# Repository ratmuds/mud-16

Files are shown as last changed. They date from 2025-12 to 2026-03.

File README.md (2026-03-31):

# mud-16

a little retro console with a Motorola 68000 and FPGA PPU

# firmware

`ppu.sv` is the Verilog code for the PPU. This is close to what will be the renderer of the game console. `main.cpp` is currently a test bench that gets the display output from the PPU and renders it with Raylib, as well as simulating the CPU bus arbitration and SRAM VRAM access

# features

-   3.5" IPS Display
-   D-pad and ABXY buttons
-   27 MHz FPGA
-   Rechargable Battery
-   512 KB of SRAM

## why

I think that the GameBoy and other retro game console are really cool, and I want to make my own console. But I didn't want to just emulate it, I wanted to use a real retro CPU and make my own PPU (picture processing unit) with a FPGA.

## how

The CPU is the brain pretty much. It handles all the game logic and stuff. It's connected to 512 KB of SRAM which the first part of it is allocated to VRAM. The VRAM is used by the FPGA. The CPU needs to go through level shifters down to 3.3V, and the CPU and FPGA needs to handle bus arbitration properly, otherwise they will fight over the bus and everything will become a mess. The FPGA will request for the bus at the beginning of each frame where they will essentially perform a handshake and the bus will be passed to the FPGA. The FPGA then accesses all the VRAM it needs and then gives back control to the CPU.

The display will be running in 8 bit parallel mode, since SPI is too slow.

## to use

this stuff is WIP

you'll need to flash everything to the FPGA which will load all the necessary data into RAM for the CPU. The Gowin IDE is the app you'll use to flash the Tang Nano.









# Schematic screenshots










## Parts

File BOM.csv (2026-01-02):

Item | Quantity | Cost | Notes | Link
PCB | 1 | $12.10 | JLCPCB PCB | https://jlcpcb.com/
PCB Assembly | 1 | $35.66 | PCB Assembly service | https://jlcpcb.com/
AMS1117-3.3 | 1 | $0.32 | Buck Converter | https://jlcpcb.com/partdetail/Advanced_MonolithicSystems-AMS1117_33/C6186
AMS1117-1.8 | 1 | $0.32 | Buck Converter | https://jlcpcb.com/partdetail/Advanced_MonolithicSystems-AMS1117_18/C6185
74LVC1G04GV | 2 | $0.10 | Shift Register | https://jlcpcb.com/partdetail/TECHPUBLIC-74LVC1G04GV/C19829589
SN74LVC8T245PW | 7 | $1.92 | Level Shifter | https://jlcpcb.com/partdetail/TexasInstruments-SN74LVC8T245PW/C1523276
Female Pin Header | 1 | $2.44 | 1x40 Female Pin Header | https://www.aliexpress.us/item/2255801012106911.html?curPageLogUid=q13fcpg1TWGx&utparam-url=scene%3Asearch|query_from%3A|x_object_id%3A4001198421663|_p_origin_prod%3A
MC68000P12 DIP-64 | 1 | $4.96 | m68k CPU 12 MHz | https://www.ebay.com/itm/315746399382?_skw=MC68000P12&itmmeta=01KCJA2ZDMD3JFW4K6QCRVRQGD|tkp%3ABFBMiveLyuRm
ILI9488 IPS No Touch | 1 | $7.67 | Display | https://www.aliexpress.us/item/3256804339619267.html?mp=1
IC DIP Sockets | 1 | $5.82 | DIP16 sockets | https://www.aliexpress.us/item/3256806149124857.html?curPageLogUid=54rKMPKbiLkA&utparam-url=scene%3Asearch|query_from%3A|x_object_id%3A1005006335439609|_p_origin_prod%3A
AS7C3513B-12TCN | 2 | $12.96 | SRAM | https://www.mouser.com/ProductDetail/Alliance-Memory/AS7C3513B-12TCN?qs=E5c5%252Bmu3i3%252BBrpzFfz%2FKzg%3D%3D
FH12-40S-0.5SH(55) | 1 | $0.62 | 40 Pin FPC Connector (display) | https://jlcpcb.com/partdetail/HRS_Hirose-FH12_40S_0_5SH_55/C202114
SN74HC165N | 2 | $1.17 | Shift Register | https://jlcpcb.com/partdetail/Ti-SN74HC165N/C2909
74HC595D | 2 | $0.53 | Shift Register | https://jlcpcb.com/partdetail/Nexperia-74HC595D_118/C5947
F32R-1A7H1-11040 | 1 | $0.91 | 40P FFC/FPC Connector | https://jlcpcb.com/partdetail/Amphenol-F32R_1A7H1_11040/C3169456
0805W8F3300T5E | 1 | $0.01 | 330Ω Resistor | https://jlcpcb.com/partdetail/UniRoyal-0805W8F3300T5E/C17630
WS2812B-HS01/W | 1 | $0.09 | RGB LED | https://jlcpcb.com/partdetail/Worldsemi-WS2812B_HS01_W/C22371521
CL21A226MAQNNNE | 2 | $0.05 | 22uF Capacitor | https://jlcpcb.com/partdetail/Samsung-CL21A226MAQNNNE/C45783
62684-501100ALF | 2 | $1.29 | 50P FFC/FPC Connector | https://jlcpcb.com/partdetail/Amphenol-62684_501100ALF/C180244
0805W8F1002T5E | 1 | $0.01 | 10kΩ Resistor | https://jlcpcb.com/partdetail/UniRoyal-0805W8F1002T5E/C17414
CL21B105KBFNNNE | 1 | $0.01 | 1uF Capacitor | https://jlcpcb.com/partdetail/Samsung-CL21B105KBFNNNE/C28323
CL21A106KAYNNNE | 1 | $0.02 | 10uF Capacitor | https://jlcpcb.com/partdetail/Samsung-CL21A106KAYNNNE/C15850
CL21B104KCFNNNE | 1 | $0.01 | 100nF Capacitor | https://jlcpcb.com/partdetail/Samsung-CL21B104KCFNNNE/C28233

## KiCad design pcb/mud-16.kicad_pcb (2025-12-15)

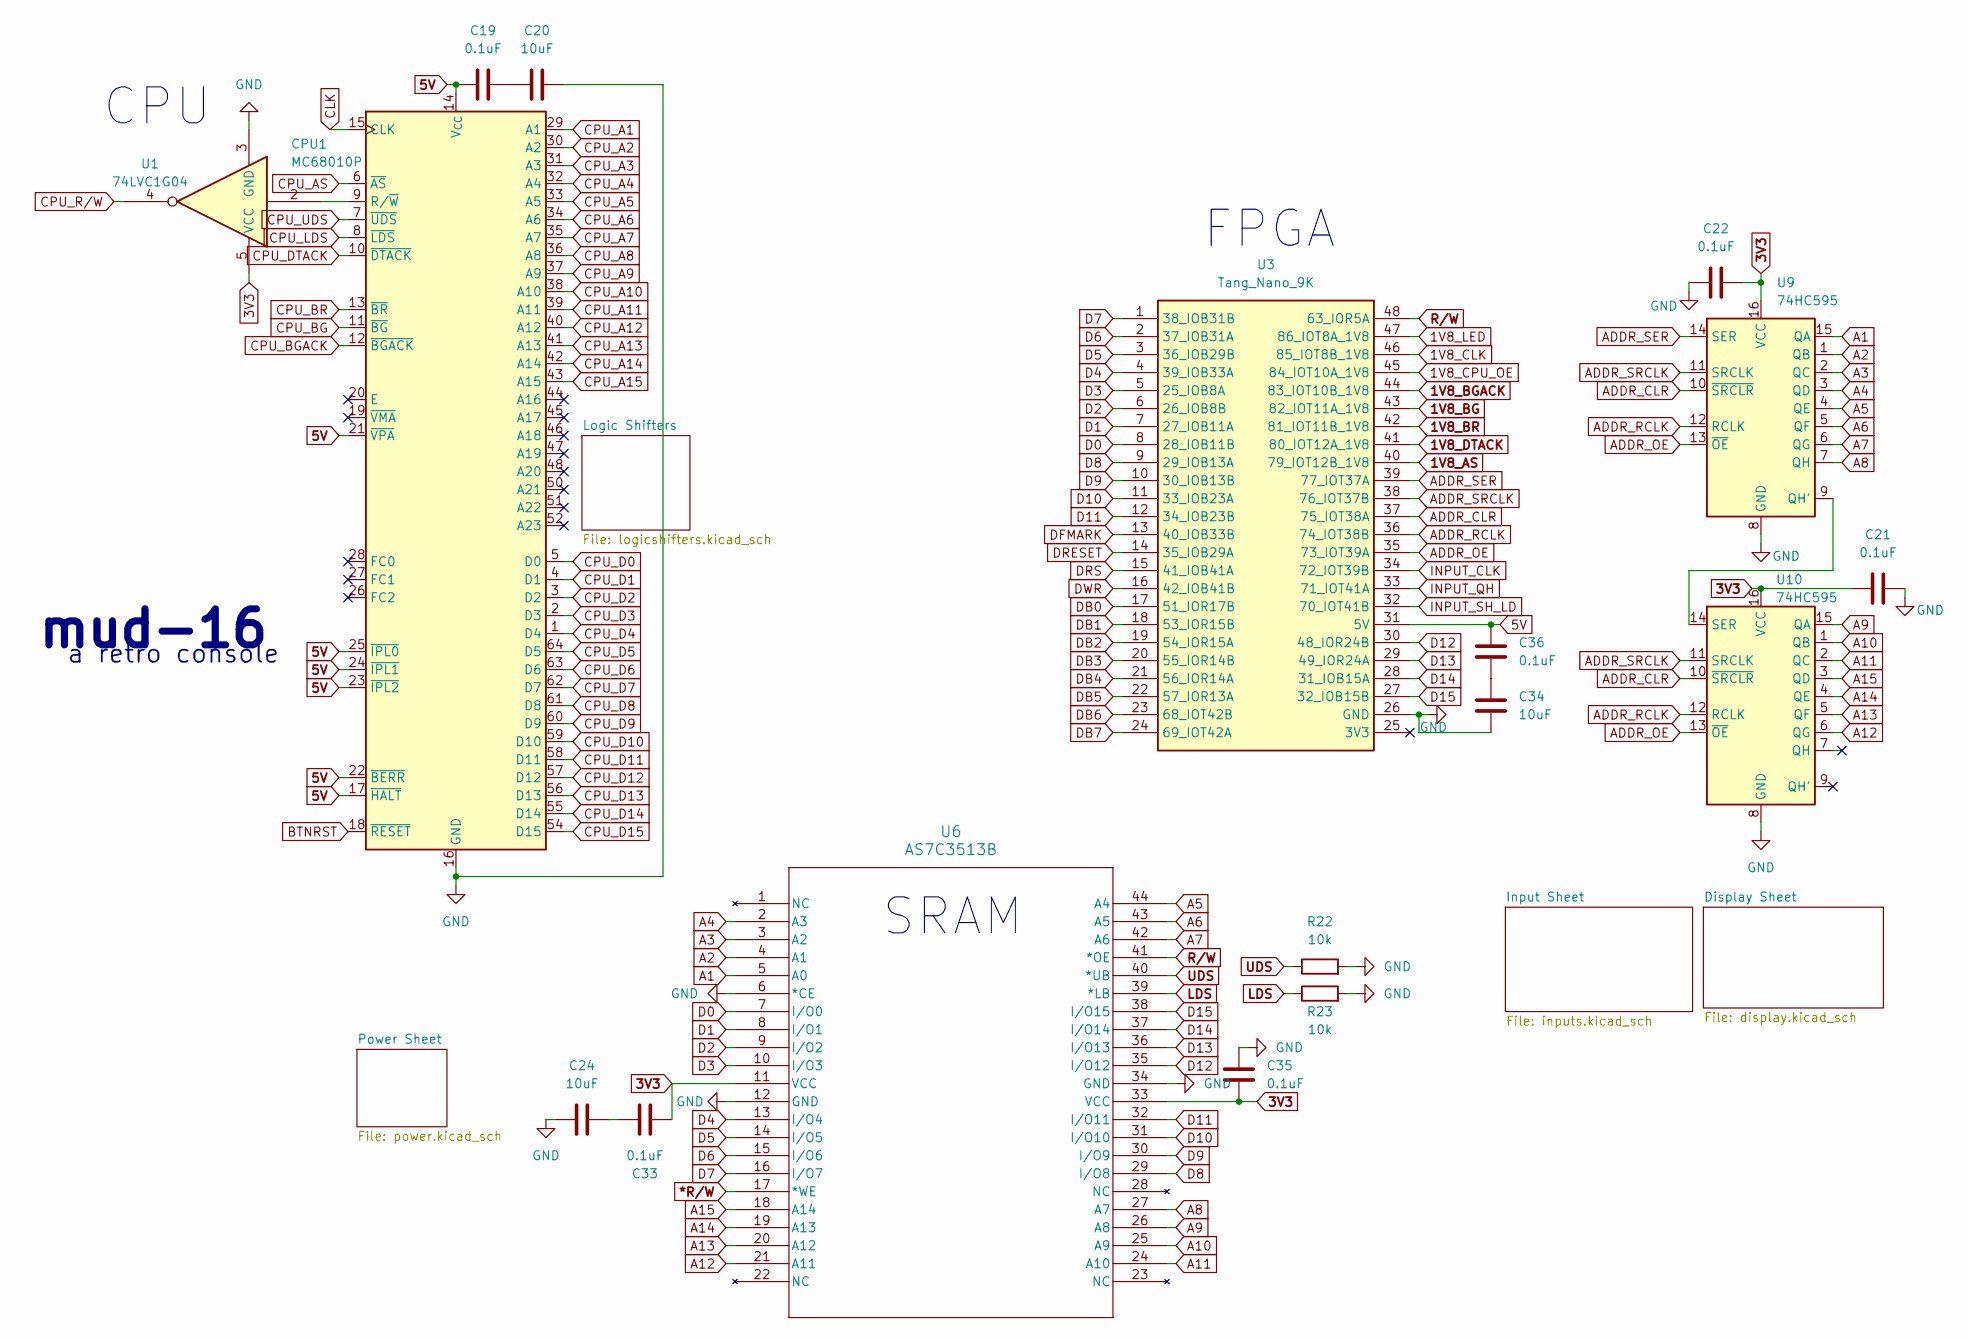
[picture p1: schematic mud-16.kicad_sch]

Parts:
C19, C21, C22, C33, C35, C36: 0.1uF; C_0805_2012Metric_Pad1.18x1.45mm_HandSolder
C20, C24, C34: 10uF; C_0805_2012Metric_Pad1.18x1.45mm_HandSolder
CPU1: MC68010P; DIP-64_W22.86mm
R22, R23: 10k; R_0805_2012Metric_Pad1.20x1.40mm_HandSolder
U1: 74LVC1G04; SOT-23-5_HandSoldering
U3: Tang_Nano_9K; DIP-48_TangNano9K
U6: AS7C3513B; TSOP-44_10P2X18P4_ALL
U9, U10: 74HC595; SOIC-16_3.9x9.9mm_P1.27mm

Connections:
1V8_AS: U3.40 (79_IOT12B_1V8); also elsewhere on the board
1V8_BG: U3.43 (82_IOT11A_1V8); also elsewhere on the board
1V8_BGACK: U3.44 (83_IOT10B_1V8); also elsewhere on the board
1V8_BR: U3.42 (81_IOT11B_1V8); also elsewhere on the board
1V8_CLK: U3.46 (85_IOT8B_1V8); also elsewhere on the board
1V8_CPU_OE: U3.45 (84_IOT10A_1V8); also elsewhere on the board
1V8_DTACK: U3.41 (80_IOT12A_1V8); also elsewhere on the board
1V8_LED: U3.47 (86_IOT8A_1V8); also elsewhere on the board
3V3: C21.1, C22.2, C33.1, C35.2, U1.5 (VCC), U6.11 (VCC), U6.33 (VCC), U9.16 (VCC), U10.16 (VCC); also elsewhere on the board
5V: C19.1, C36.1, CPU1.14 (V_{CC}), CPU1.17 (~HALT), CPU1.21 (~VPA), CPU1.22 (~BERR), CPU1.23 (~IPL2), CPU1.24 (~IPL1), CPU1.25 (~IPL0), CPU1.49 (V_{CC}), U3.31 (5V); also elsewhere on the board
*R/W: U6.17 (*WE); also elsewhere on the board
A1: U6.5 (A0), U9.15 (QA); also elsewhere on the board
A2: U6.4 (A1), U9.1 (QB); also elsewhere on the board
A3: U6.3 (A2), U9.2 (QC); also elsewhere on the board
A4: U6.2 (A3), U9.3 (QD); also elsewhere on the board
A5: U6.44 (A4), U9.4 (QE); also elsewhere on the board
A6: U6.43 (A5), U9.5 (QF); also elsewhere on the board
A7: U6.42 (A6), U9.6 (QG); also elsewhere on the board
A8: U6.27 (A7), U9.7 (QH); also elsewhere on the board
A9: U6.26 (A8), U10.15 (QA); also elsewhere on the board
A10: U6.25 (A9), U10.1 (QB); also elsewhere on the board
A11: U6.24 (A10), U10.2 (QC); also elsewhere on the board
A12: U6.21 (A11), U10.6 (QG); also elsewhere on the board
A13: U6.20 (A12), U10.5 (QF); also elsewhere on the board
A14: U6.19 (A13), U10.4 (QE); also elsewhere on the board
A15: U6.18 (A14), U10.3 (QD); also elsewhere on the board
ADDR_CLR: U3.37 (75_IOT38A), U9.10 (~SRCLR), U10.10 (~SRCLR)
ADDR_OE: U3.35 (73_IOT39A), U9.13 (~OE), U10.13 (~OE)
ADDR_RCLK: U3.36 (74_IOT38B), U9.12 (RCLK), U10.12 (RCLK)
ADDR_SER: U3.39 (77_IOT37A), U9.14 (SER)
ADDR_SRCLK: U3.38 (76_IOT37B), U9.11 (SRCLK), U10.11 (SRCLK)
BTNRST: CPU1.18 (~RESET); also elsewhere on the board
CLK: CPU1.15 (CLK); also elsewhere on the board
CPU_A1: CPU1.29 (A1); also elsewhere on the board
CPU_A2: CPU1.30 (A2); also elsewhere on the board
CPU_A3: CPU1.31 (A3); also elsewhere on the board
CPU_A4: CPU1.32 (A4); also elsewhere on the board
CPU_A5: CPU1.33 (A5); also elsewhere on the board
CPU_A6: CPU1.34 (A6); also elsewhere on the board
CPU_A7: CPU1.35 (A7); also elsewhere on the board
CPU_A8: CPU1.36 (A8); also elsewhere on the board
CPU_A9: CPU1.37 (A9); also elsewhere on the board
CPU_A10: CPU1.38 (A10); also elsewhere on the board
CPU_A11: CPU1.39 (A11); also elsewhere on the board
CPU_A12: CPU1.40 (A12); also elsewhere on the board
CPU_A13: CPU1.41 (A13); also elsewhere on the board
CPU_A14: CPU1.42 (A14); also elsewhere on the board
CPU_A15: CPU1.43 (A15); also elsewhere on the board
CPU_AS: CPU1.6 (~AS); also elsewhere on the board
CPU_BG: CPU1.11 (~BG); also elsewhere on the board
CPU_BGACK: CPU1.12 (~BGACK); also elsewhere on the board
CPU_BR: CPU1.13 (~BR); also elsewhere on the board
CPU_D0: CPU1.5 (D0); also elsewhere on the board
CPU_D1: CPU1.4 (D1); also elsewhere on the board
CPU_D2: CPU1.3 (D2); also elsewhere on the board
CPU_D3: CPU1.2 (D3); also elsewhere on the board
CPU_D4: CPU1.1 (D4); also elsewhere on the board
CPU_D5: CPU1.64 (D5); also elsewhere on the board
CPU_D6: CPU1.63 (D6); also elsewhere on the board
CPU_D7: CPU1.62 (D7); also elsewhere on the board
CPU_D8: CPU1.61 (D8); also elsewhere on the board
CPU_D9: CPU1.60 (D9); also elsewhere on the board
CPU_D10: CPU1.59 (D10); also elsewhere on the board
CPU_D11: CPU1.58 (D11); also elsewhere on the board
CPU_D12: CPU1.57 (D12); also elsewhere on the board
CPU_D13: CPU1.56 (D13); also elsewhere on the board
CPU_D14: CPU1.55 (D14); also elsewhere on the board
CPU_D15: CPU1.54 (D15); also elsewhere on the board
CPU_DTACK: CPU1.10 (~DTACK); also elsewhere on the board
CPU_LDS: CPU1.8 (~LDS); also elsewhere on the board
CPU_R/W: U1.4; also elsewhere on the board
CPU_UDS: CPU1.7 (~UDS); also elsewhere on the board
D0: U3.8 (28_IOB11B), U6.7 (I/O0); also elsewhere on the board
D1: U3.7 (27_IOB11A), U6.8 (I/O1); also elsewhere on the board
D2: U3.6 (26_IOB8B), U6.9 (I/O2); also elsewhere on the board
D3: U3.5 (25_IOB8A), U6.10 (I/O3); also elsewhere on the board
D4: U3.4 (39_IOB33A), U6.13 (I/O4); also elsewhere on the board
D5: U3.3 (36_IOB29B), U6.14 (I/O5); also elsewhere on the board
D6: U3.2 (37_IOB31A), U6.15 (I/O6); also elsewhere on the board
D7: U3.1 (38_IOB31B), U6.16 (I/O7); also elsewhere on the board
D8: U3.9 (29_IOB13A), U6.29 (I/O8); also elsewhere on the board
D9: U3.10 (30_IOB13B), U6.30 (I/O9); also elsewhere on the board
D10: U3.11 (33_IOB23A), U6.31 (I/O10); also elsewhere on the board
D11: U3.12 (34_IOB23B), U6.32 (I/O11); also elsewhere on the board
D12: U3.30 (48_IOR24B), U6.35 (I/O12); also elsewhere on the board
D13: U3.29 (49_IOR24A), U6.36 (I/O13); also elsewhere on the board
D14: U3.28 (31_IOB15A), U6.37 (I/O14); also elsewhere on the board
D15: U3.27 (32_IOB15B), U6.38 (I/O15); also elsewhere on the board
DB0: U3.17 (51_IOR17B); also elsewhere on the board
DB1: U3.18 (53_IOR15B); also elsewhere on the board
DB2: U3.19 (54_IOR15A); also elsewhere on the board
DB3: U3.20 (55_IOR14B); also elsewhere on the board
DB4: U3.21 (56_IOR14A); also elsewhere on the board
DB5: U3.22 (57_IOR13A); also elsewhere on the board
DB6: U3.23 (68_IOT42B); also elsewhere on the board
DB7: U3.24 (69_IOT42A); also elsewhere on the board
DFMARK: U3.13 (40_IOB33B); also elsewhere on the board
DRESET: U3.14 (35_IOB29A); also elsewhere on the board
DRS: U3.15 (41_IOB41A); also elsewhere on the board
DWR: U3.16 (42_IOB41B); also elsewhere on the board
GND: C20.2, C21.2, C22.1, C24.1, C34.2, C35.1, CPU1.16 (GND), CPU1.53 (GND), R22.2, R23.2, U1.3 (GND), U3.26 (GND), U6.6 (*CE), U6.12 (GND), U6.34 (GND), U9.8 (GND), U10.8 (GND); also elsewhere on the board
INPUT_CLK: U3.34 (72_IOT39B); also elsewhere on the board
INPUT_QH: U3.33 (71_IOT41A); also elsewhere on the board
INPUT_SH_LD: U3.32 (70_IOT41B); also elsewhere on the board
LDS: R23.1, U6.39 (*LB); also elsewhere on the board
unnamed: C19.2, C20.1
unnamed: C24.2, C33.2
unnamed: C34.1, C36.2
unnamed: CPU1.9 (R/~W), U1.2
unnamed: U9.9 (QH'), U10.14 (SER)
R/W: U3.48 (63_IOR5A), U6.41 (*OE); also elsewhere on the board
UDS: R22.1, U6.40 (*UB); also elsewhere on the board

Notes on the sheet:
mud-16
SRAM
FPGA
a retro console
CPU

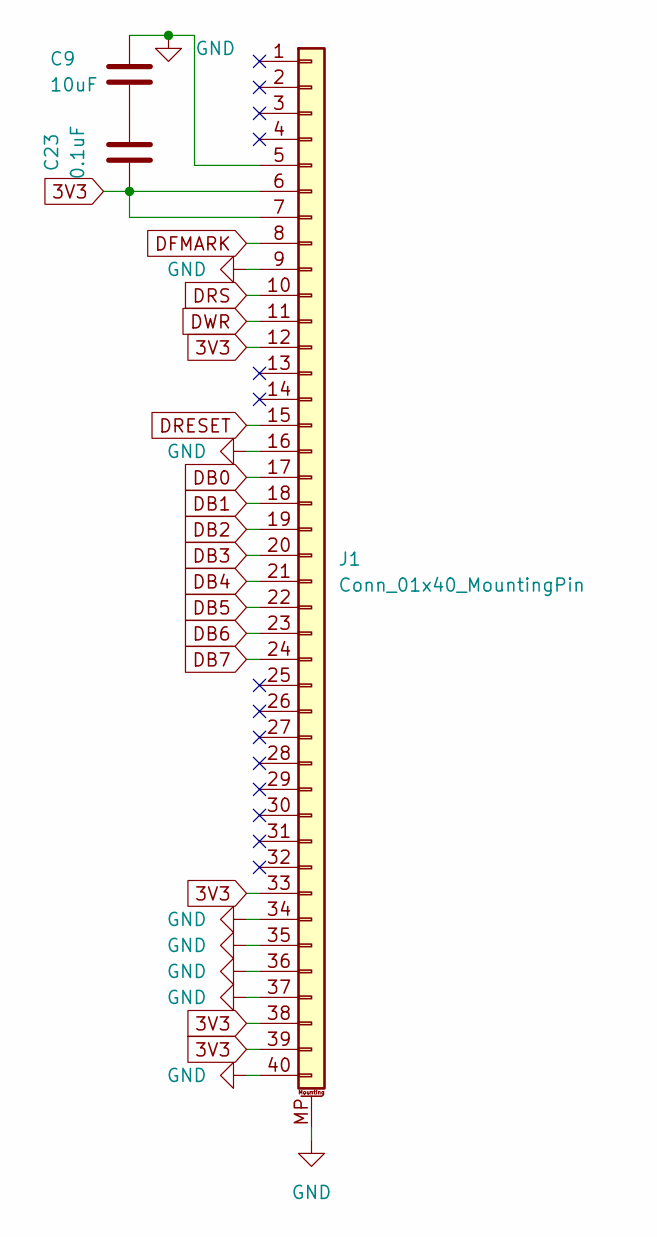
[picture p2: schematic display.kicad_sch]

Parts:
C9: 10uF; C_0805_2012Metric_Pad1.18x1.45mm_HandSolder
C23: 0.1uF; C_0805_2012Metric_Pad1.18x1.45mm_HandSolder
J1: Conn_01x40_MountingPin; Amphenol_F32R-1A7x1-11040_1x40-1MP_P0.5mm_Horizontal

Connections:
3V3: C23.1, J1.6, J1.7, J1.12, J1.33, J1.38, J1.39; also elsewhere on the board
DB0: J1.17; also elsewhere on the board
DB1: J1.18; also elsewhere on the board
DB2: J1.19; also elsewhere on the board
DB3: J1.20; also elsewhere on the board
DB4: J1.21; also elsewhere on the board
DB5: J1.22; also elsewhere on the board
DB6: J1.23; also elsewhere on the board
DB7: J1.24; also elsewhere on the board
DFMARK: J1.8; also elsewhere on the board
DRESET: J1.15; also elsewhere on the board
DRS: J1.10; also elsewhere on the board
DWR: J1.11; also elsewhere on the board
GND: C9.1, J1.5, J1.9, J1.16, J1.34, J1.35, J1.36, J1.37, J1.40, J1.MP (MountPin); also elsewhere on the board
unnamed: C9.2, C23.2

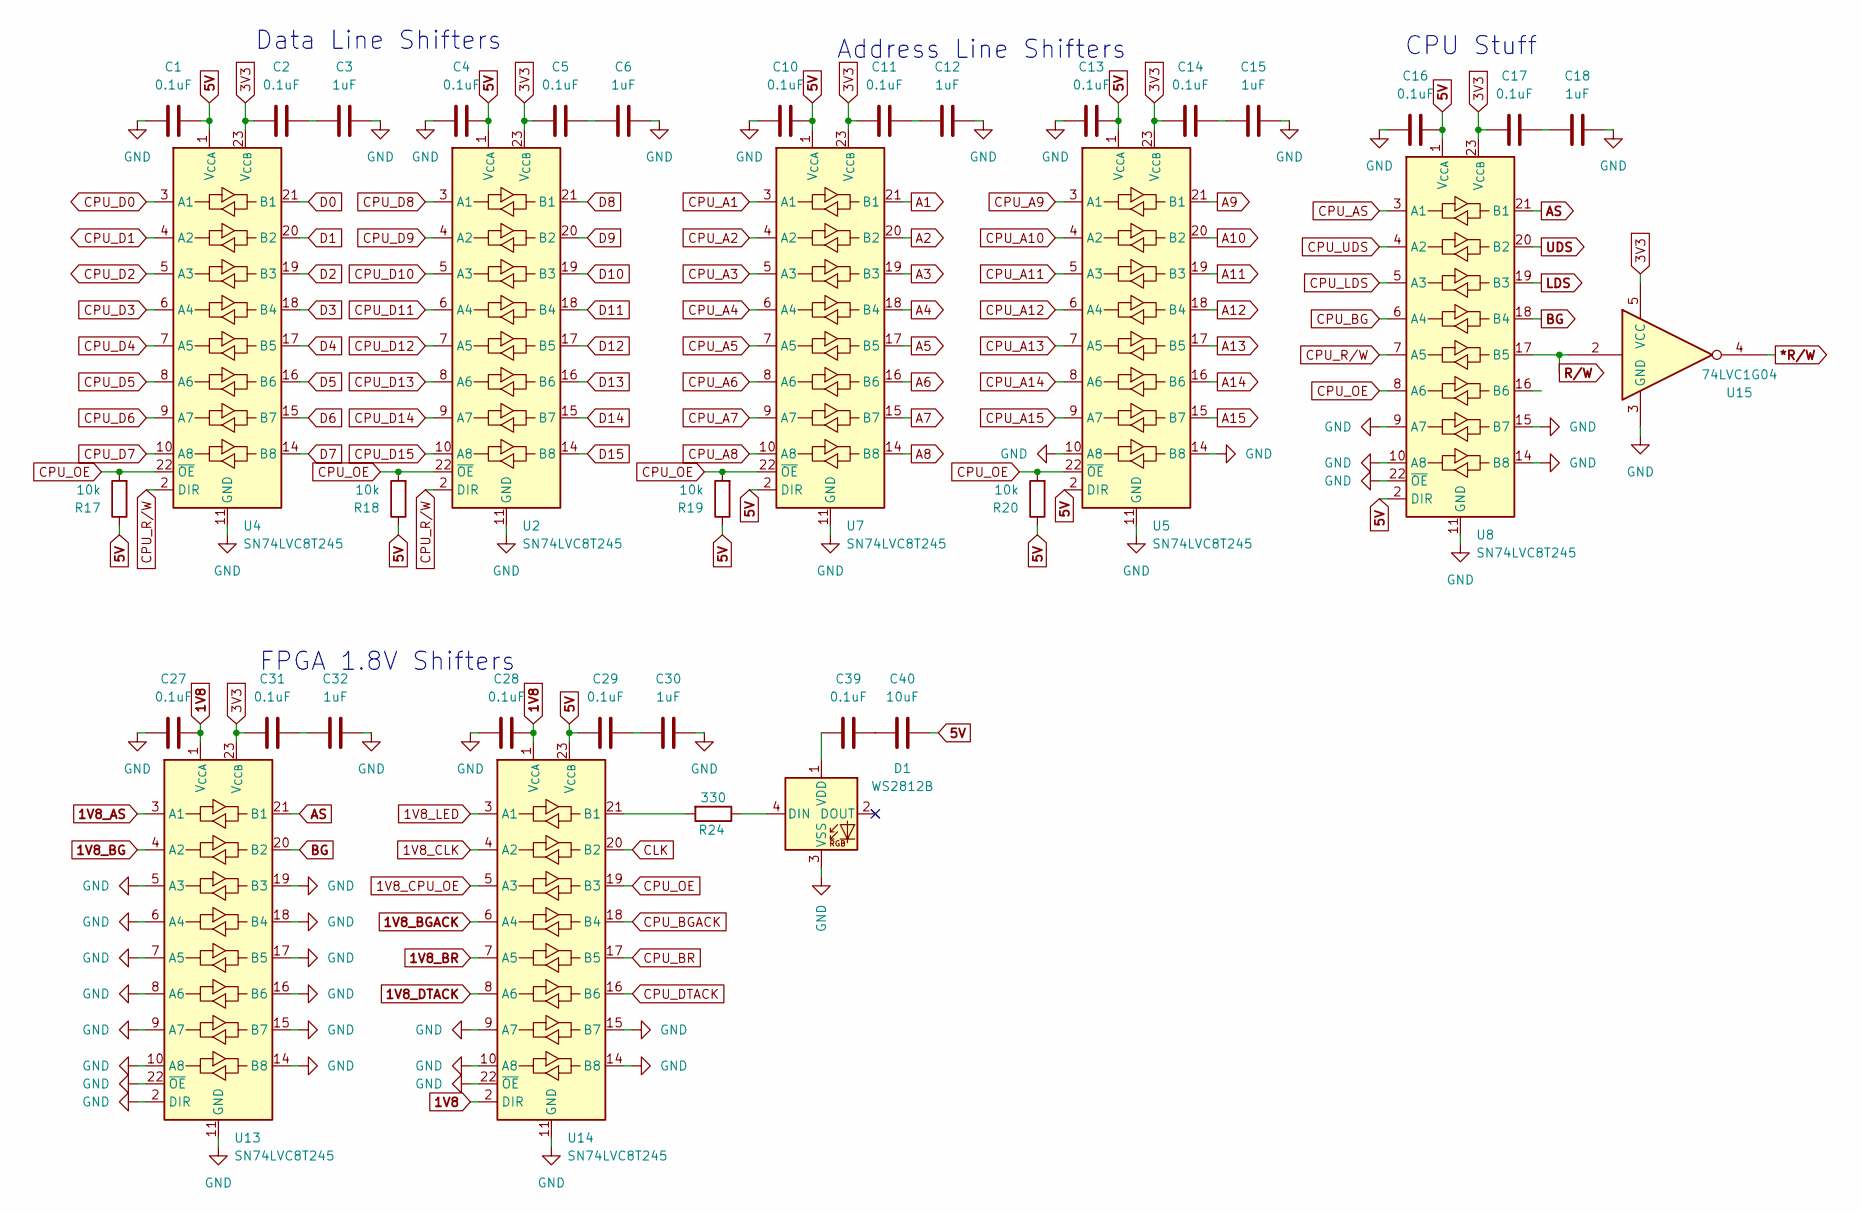
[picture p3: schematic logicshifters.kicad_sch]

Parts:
C1, C2, C4, C5, C10, C11, C13, C14, C16, C17, C27, C28, C29, C31, C39: 0.1uF; C_0805_2012Metric_Pad1.18x1.45mm_HandSolder
C3, C6, C12, C15, C18, C30, C32: 1uF; C_0805_2012Metric_Pad1.18x1.45mm_HandSolder
C40: 10uF; C_0805_2012Metric_Pad1.18x1.45mm_HandSolder
D1: WS2812B; LED_WS2812B_PLCC4_5.0x5.0mm_P3.2mm
R17, R18, R19, R20: 10k; R_0805_2012Metric_Pad1.20x1.40mm_HandSolder
R24: 330; R_0805_2012Metric_Pad1.20x1.40mm_HandSolder
U2, U4, U5, U7, U8, U13, U14: SN74LVC8T245; TSSOP-24_4.4x7.8mm_P0.65mm
U15: 74LVC1G04; SOT-23-5_HandSoldering

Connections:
1V8: C27.2, C28.2, U13.1 (V_{CCA}), U14.1 (V_{CCA}), U14.2 (DIR); also elsewhere on the board
1V8_AS: U13.3 (A1); also elsewhere on the board
1V8_BG: U13.4 (A2); also elsewhere on the board
1V8_BGACK: U14.6 (A4); also elsewhere on the board
1V8_BR: U14.7 (A5); also elsewhere on the board
1V8_CLK: U14.4 (A2); also elsewhere on the board
1V8_CPU_OE: U14.5 (A3); also elsewhere on the board
1V8_DTACK: U14.8 (A6); also elsewhere on the board
1V8_LED: U14.3 (A1); also elsewhere on the board
3V3: C2.1, C5.1, C11.1, C14.1, C17.1, C31.1, U2.23 (V_{CCB}), U2.24 (V_{CCB}), U4.23 (V_{CCB}), U4.24 (V_{CCB}), U5.23 (V_{CCB}), U5.24 (V_{CCB}), U7.23 (V_{CCB}), U7.24 (V_{CCB}), U8.23 (V_{CCB}), U8.24 (V_{CCB}), U13.23 (V_{CCB}), U13.24 (V_{CCB}), U15.5 (VCC); also elsewhere on the board
5V: C1.2, C4.2, C10.2, C13.2, C16.2, C29.1, C40.2, R17.1, R18.1, R19.1, R20.1, U2.1 (V_{CCA}), U4.1 (V_{CCA}), U5.1 (V_{CCA}), U5.2 (DIR), U7.1 (V_{CCA}), U7.2 (DIR), U8.1 (V_{CCA}), U8.2 (DIR), U14.23 (V_{CCB}), U14.24 (V_{CCB}); also elsewhere on the board
*R/W: U15.4; also elsewhere on the board
A1: U7.21 (B1); also elsewhere on the board
A2: U7.20 (B2); also elsewhere on the board
A3: U7.19 (B3); also elsewhere on the board
A4: U7.18 (B4); also elsewhere on the board
A5: U7.17 (B5); also elsewhere on the board
A6: U7.16 (B6); also elsewhere on the board
A7: U7.15 (B7); also elsewhere on the board
A8: U7.14 (B8); also elsewhere on the board
A9: U5.21 (B1); also elsewhere on the board
A10: U5.20 (B2); also elsewhere on the board
A11: U5.19 (B3); also elsewhere on the board
A12: U5.18 (B4); also elsewhere on the board
A13: U5.17 (B5); also elsewhere on the board
A14: U5.16 (B6); also elsewhere on the board
A15: U5.15 (B7); also elsewhere on the board
AS: U8.21 (B1), U13.21 (B1)
BG: U8.18 (B4), U13.20 (B2)
CLK: U14.20 (B2); also elsewhere on the board
CPU_A1: U7.3 (A1); also elsewhere on the board
CPU_A2: U7.4 (A2); also elsewhere on the board
CPU_A3: U7.5 (A3); also elsewhere on the board
CPU_A4: U7.6 (A4); also elsewhere on the board
CPU_A5: U7.7 (A5); also elsewhere on the board
CPU_A6: U7.8 (A6); also elsewhere on the board
CPU_A7: U7.9 (A7); also elsewhere on the board
CPU_A8: U7.10 (A8); also elsewhere on the board
CPU_A9: U5.3 (A1); also elsewhere on the board
CPU_A10: U5.4 (A2); also elsewhere on the board
CPU_A11: U5.5 (A3); also elsewhere on the board
CPU_A12: U5.6 (A4); also elsewhere on the board
CPU_A13: U5.7 (A5); also elsewhere on the board
CPU_A14: U5.8 (A6); also elsewhere on the board
CPU_A15: U5.9 (A7); also elsewhere on the board
CPU_AS: U8.3 (A1); also elsewhere on the board
CPU_BG: U8.6 (A4); also elsewhere on the board
CPU_BGACK: U14.18 (B4); also elsewhere on the board
CPU_BR: U14.17 (B5); also elsewhere on the board
CPU_D0: U4.3 (A1); also elsewhere on the board
CPU_D1: U4.4 (A2); also elsewhere on the board
CPU_D2: U4.5 (A3); also elsewhere on the board
CPU_D3: U4.6 (A4); also elsewhere on the board
CPU_D4: U4.7 (A5); also elsewhere on the board
CPU_D5: U4.8 (A6); also elsewhere on the board
CPU_D6: U4.9 (A7); also elsewhere on the board
CPU_D7: U4.10 (A8); also elsewhere on the board
CPU_D8: U2.3 (A1); also elsewhere on the board
CPU_D9: U2.4 (A2); also elsewhere on the board
CPU_D10: U2.5 (A3); also elsewhere on the board
CPU_D11: U2.6 (A4); also elsewhere on the board
CPU_D12: U2.7 (A5); also elsewhere on the board
CPU_D13: U2.8 (A6); also elsewhere on the board
CPU_D14: U2.9 (A7); also elsewhere on the board
CPU_D15: U2.10 (A8); also elsewhere on the board
CPU_DTACK: U14.16 (B6); also elsewhere on the board
CPU_LDS: U8.5 (A3); also elsewhere on the board
CPU_OE: R17.2, R18.2, R19.2, R20.2, U2.22 (~OE), U4.22 (~OE), U5.22 (~OE), U7.22 (~OE), U8.8 (A6), U14.19 (B3)
CPU_R/W: U2.2 (DIR), U4.2 (DIR), U8.7 (A5); also elsewhere on the board
CPU_UDS: U8.4 (A2); also elsewhere on the board
D0: U4.21 (B1); also elsewhere on the board
D1: U4.20 (B2); also elsewhere on the board
D2: U4.19 (B3); also elsewhere on the board
D3: U4.18 (B4); also elsewhere on the board
D4: U4.17 (B5); also elsewhere on the board
D5: U4.16 (B6); also elsewhere on the board
D6: U4.15 (B7); also elsewhere on the board
D7: U4.14 (B8); also elsewhere on the board
D8: U2.21 (B1); also elsewhere on the board
D9: U2.20 (B2); also elsewhere on the board
D10: U2.19 (B3); also elsewhere on the board
D11: U2.18 (B4); also elsewhere on the board
D12: U2.17 (B5); also elsewhere on the board
D13: U2.16 (B6); also elsewhere on the board
D14: U2.15 (B7); also elsewhere on the board
D15: U2.14 (B8); also elsewhere on the board
GND: C1.1, C3.2, C4.1, C6.2, C10.1, C12.2, C13.1, C15.2, C16.1, C18.2, C27.1, C28.1, C30.2, C32.2, D1.3 (VSS), U2.11 (GND), U2.12 (GND), U2.13 (GND), U4.11 (GND), U4.12 (GND), U4.13 (GND), U5.10 (A8), U5.11 (GND), U5.12 (GND), U5.13 (GND), U5.14 (B8), U7.11 (GND), U7.12 (GND), U7.13 (GND), U8.9 (A7), U8.10 (A8), U8.11 (GND), U8.12 (GND), U8.13 (GND), U8.14 (B8), U8.15 (B7), U8.22 (~OE), U13.2 (DIR), U13.5 (A3), U13.6 (A4), U13.7 (A5), U13.8 (A6), U13.9 (A7), U13.10 (A8), U13.11 (GND), U13.12 (GND), U13.13 (GND), U13.14 (B8), U13.15 (B7), U13.16 (B6), U13.17 (B5), U13.18 (B4), U13.19 (B3), U13.22 (~OE), U14.9 (A7), U14.10 (A8), U14.11 (GND), U14.12 (GND), U14.13 (GND), U14.14 (B8), U14.15 (B7), U14.22 (~OE), U15.3 (GND); also elsewhere on the board
LDS: U8.19 (B3); also elsewhere on the board
unnamed: C2.2, C3.1
unnamed: C5.2, C6.1
unnamed: C11.2, C12.1
unnamed: C14.2, C15.1
unnamed: C17.2, C18.1
unnamed: C29.2, C30.1
unnamed: C31.2, C32.1
unnamed: C39.2, C40.1
unnamed: D1.4 (DIN), R24.1
unnamed: C39.1, D1.1 (VDD)
unnamed: R24.2, U14.21 (B1)
R/W: U8.17 (B5), U15.2; also elsewhere on the board
UDS: U8.20 (B2); also elsewhere on the board

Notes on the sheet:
CPU Stuff
Data Line Shifters
FPGA 1.8V Shifters
Address Line Shifters

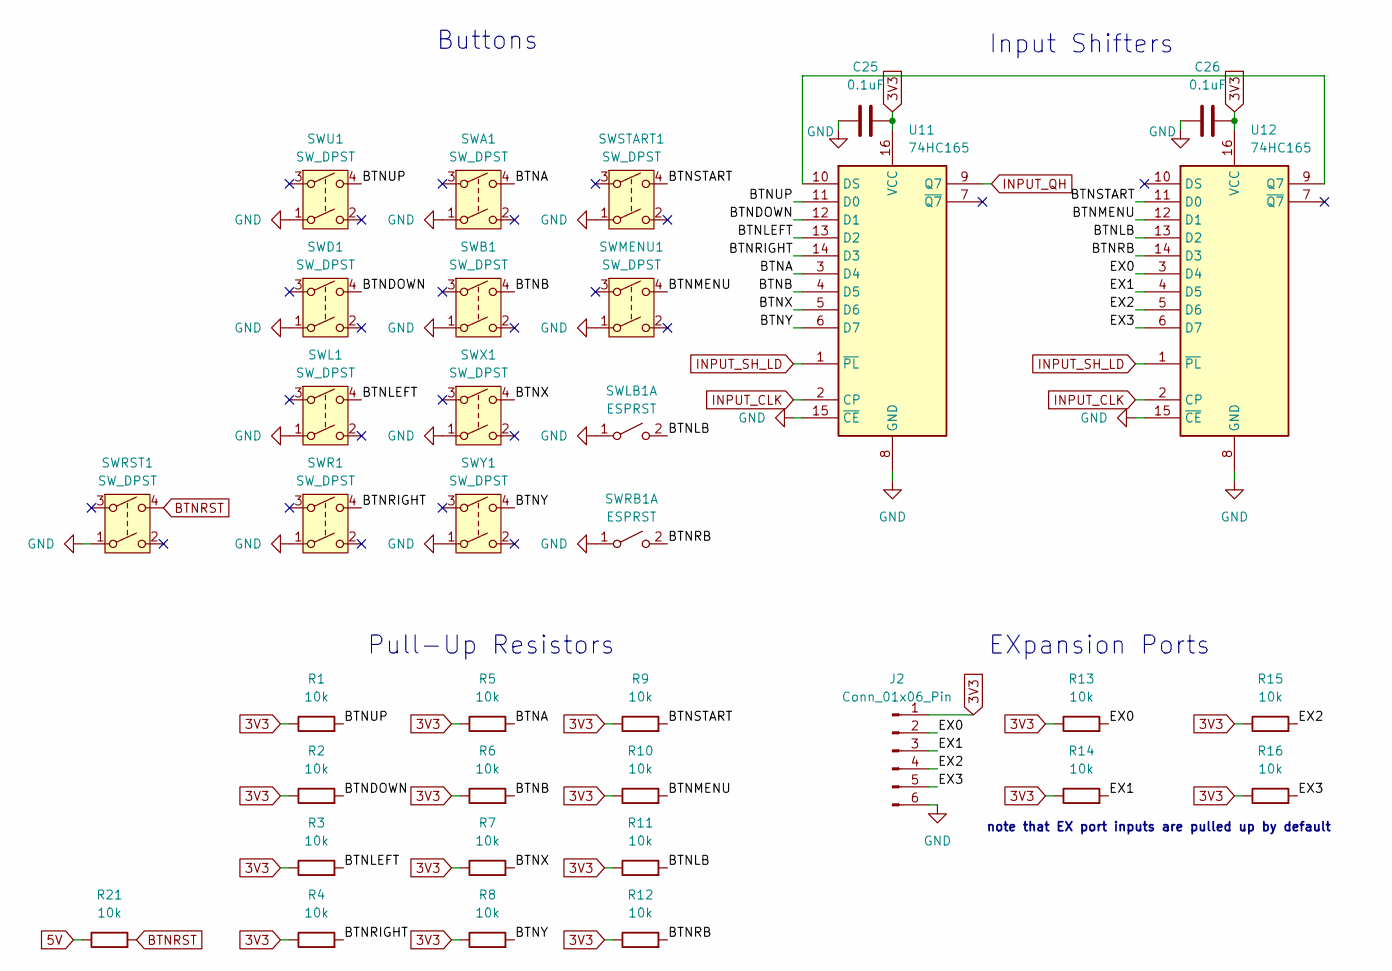
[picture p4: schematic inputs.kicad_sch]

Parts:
C25, C26: 0.1uF; C_0805_2012Metric_Pad1.18x1.45mm_HandSolder
J2: Conn_01x06_Pin; PinSocket_1x06_P2.54mm_Vertical
R1, R2, R3, R4, R5, R6, R7, R8, R9, R10, R11, R12, R13, R14, R15, R16, R21: 10k; R_0805_2012Metric_Pad1.20x1.40mm_HandSolder
SWA1: SW_DPST; SW_PUSH_6mm
SWB1: SW_DPST; SW_PUSH_6mm
SWD1: SW_DPST; SW_PUSH_6mm
SWL1: SW_DPST; SW_PUSH_6mm
SWLB1: ESPRST; SW_SIDE_PUSH_3x6mm
SWMENU1: SW_DPST; SW_PUSH_6mm
SWR1: SW_DPST; SW_PUSH_6mm
SWRB1: ESPRST; SW_SIDE_PUSH_3x6mm
SWRST1: SW_DPST; SW_PUSH_6mm
SWSTART1: SW_DPST; SW_PUSH_6mm
SWU1: SW_DPST; SW_PUSH_6mm
SWX1: SW_DPST; SW_PUSH_6mm
SWY1: SW_DPST; SW_PUSH_6mm
U11, U12: 74HC165; DIP-16_W7.62mm

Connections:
3V3: C25.2, C26.2, J2.1, R1.1, R2.1, R3.1, R4.1, R5.1, R6.1, R7.1, R8.1, R9.1, R10.1, R11.1, R12.1, R13.1, R14.1, R15.1, R16.1, U11.16 (VCC), U12.16 (VCC); also elsewhere on the board
5V: R21.1; also elsewhere on the board
/Input Sheet/BTNA: R5.2, SWA1.4, U11.3 (D4)
/Input Sheet/BTNB: R6.2, SWB1.4, U11.4 (D5)
/Input Sheet/BTNDOWN: R2.2, SWD1.4, U11.12 (D1)
/Input Sheet/BTNLB: R11.2, SWLB1.2 (B), U12.13 (D2)
/Input Sheet/BTNLEFT: R3.2, SWL1.4, U11.13 (D2)
/Input Sheet/BTNMENU: R10.2, SWMENU1.4, U12.12 (D1)
/Input Sheet/BTNRB: R12.2, SWRB1.2 (B), U12.14 (D3)
/Input Sheet/BTNRIGHT: R4.2, SWR1.4, U11.14 (D3)
/Input Sheet/BTNSTART: R9.2, SWSTART1.4, U12.11 (D0)
/Input Sheet/BTNUP: R1.2, SWU1.4, U11.11 (D0)
/Input Sheet/BTNX: R7.2, SWX1.4, U11.5 (D6)
/Input Sheet/BTNY: R8.2, SWY1.4, U11.6 (D7)
/Input Sheet/EX0: J2.2, R13.2, U12.3 (D4)
/Input Sheet/EX1: J2.3, R14.2, U12.4 (D5)
/Input Sheet/EX2: J2.4, R15.2, U12.5 (D6)
/Input Sheet/EX3: J2.5, R16.2, U12.6 (D7)
BTNRST: R21.2, SWRST1.4; also elsewhere on the board
GND: C25.1, C26.1, J2.6, SWA1.1, SWB1.1, SWD1.1, SWL1.1, SWLB1.1 (A), SWMENU1.1, SWR1.1, SWRB1.1 (A), SWRST1.1, SWSTART1.1, SWU1.1, SWX1.1, SWY1.1, U11.8 (GND), U11.15 (~CE), U12.8 (GND), U12.15 (~CE); also elsewhere on the board
INPUT_CLK: U11.2 (CP), U12.2 (CP); also elsewhere on the board
INPUT_QH: U11.9 (Q7); also elsewhere on the board
INPUT_SH_LD: U11.1 (~PL), U12.1 (~PL); also elsewhere on the board
unnamed: U11.10 (DS), U12.9 (Q7)

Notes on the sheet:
Pull-Up Resistors
EXpansion Ports
note that EX port inputs are pulled up by default
Buttons
Input Shifters

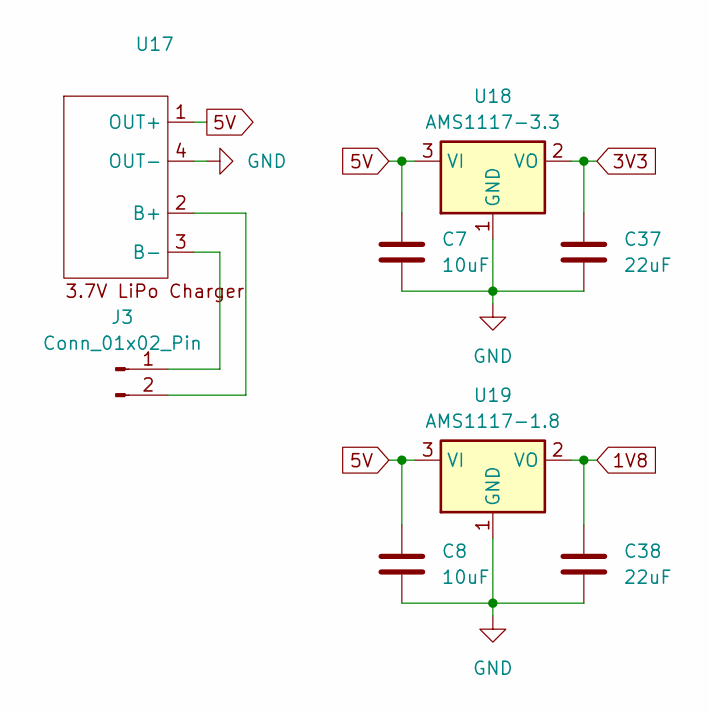
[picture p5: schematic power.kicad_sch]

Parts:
C7, C8: 10uF; C_0805_2012Metric_Pad1.18x1.45mm_HandSolder
C37, C38: 22uF; C_0805_2012Metric_Pad1.18x1.45mm_HandSolder
J3: Conn_01x02_Pin; JST_PH_S2B-PH-K_1x02_P2.00mm_Horizontal
U17: 3.7V_LiPo_Charging_Board
U18: AMS1117-3.3; SOT-223-3_TabPin2
U19: AMS1117-1.8; SOT-223-3_TabPin2

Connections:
1V8: C38.1, U19.2 (VO); also elsewhere on the board
3V3: C37.1, U18.2 (VO); also elsewhere on the board
5V: C7.1, C8.1, U17.1 (OUT+), U18.3 (VI), U19.3 (VI); also elsewhere on the board
GND: C7.2, C8.2, C37.2, C38.2, U17.4 (OUT-), U18.1 (GND), U19.1 (GND); also elsewhere on the board
unnamed: J3.1, U17.3 (B-)
unnamed: J3.2, U17.2 (B+)

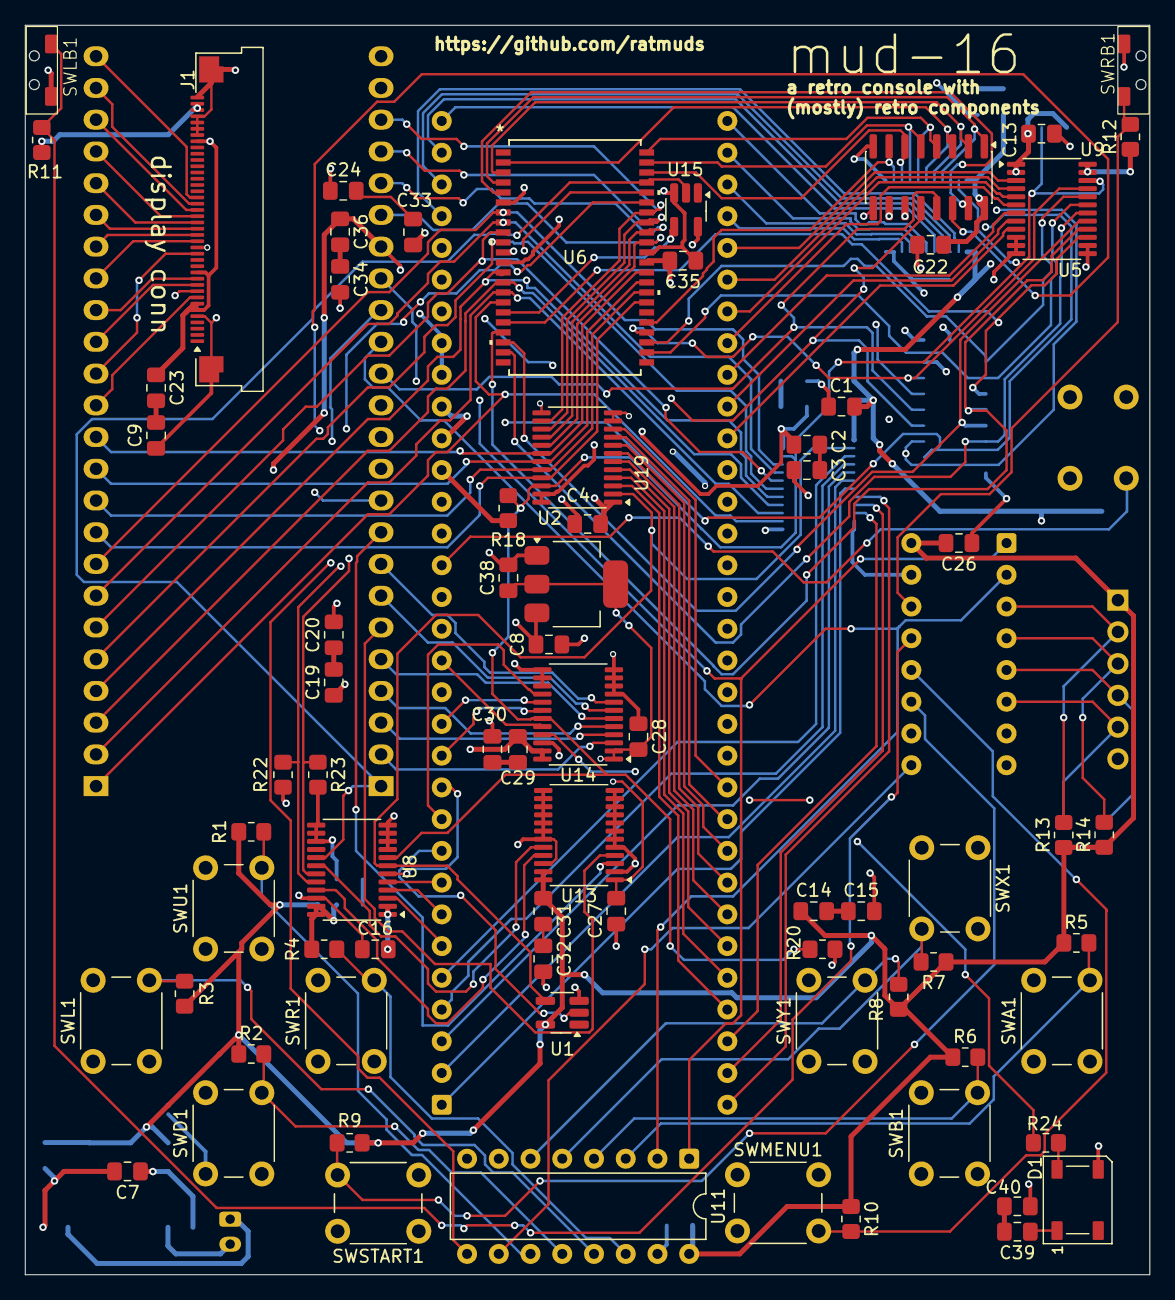
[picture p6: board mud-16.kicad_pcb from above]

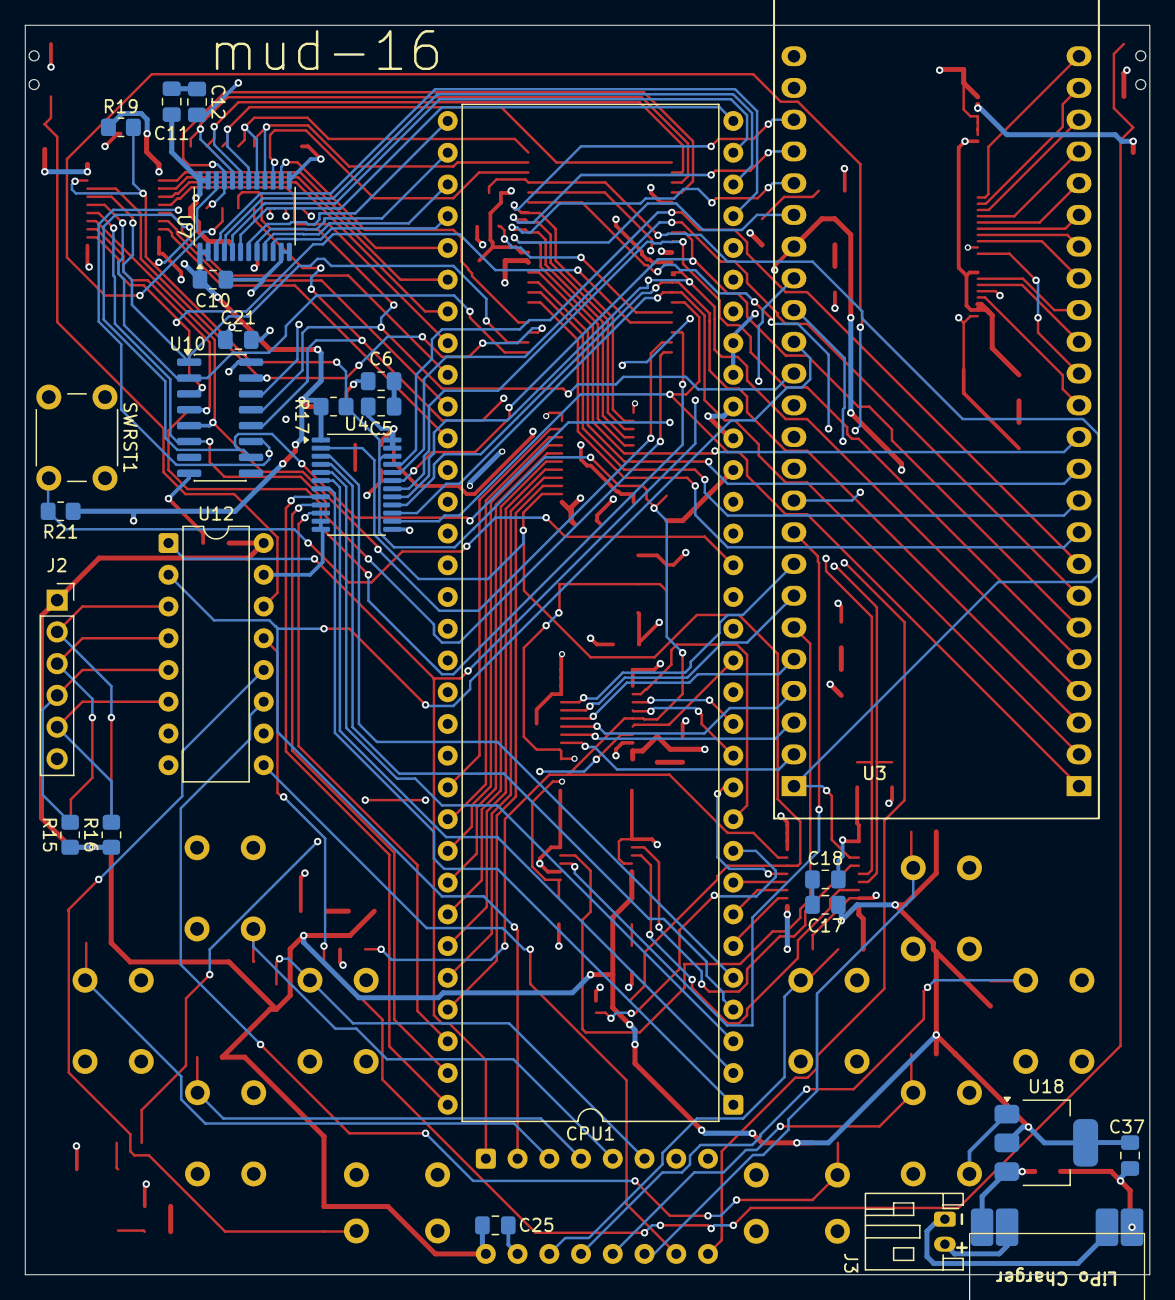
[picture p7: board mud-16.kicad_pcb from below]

Board: 4 copper layers, 90.0 x 100.0 mm, 100 parts (26 on the bottom side), 147 nets.

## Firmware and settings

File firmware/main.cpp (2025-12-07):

#include "Vppu.h"
#include "verilated.h"
#include "raylib.h"
#include "vram_init_data.h"
#include <vector>
#include <cstdint>
#include <cstring>

const int WIDTH  = 320;
const int HEIGHT = 240;
const int SCALE  = 2;
const int RAM_SIZE = 512 * 1024;

// -----------------------------------------------------------------------------
// System Simulation Class
// -----------------------------------------------------------------------------
class Mud16System {
public:
    Vppu* ppu;
    std::vector<uint8_t> ram;
    uint64_t tick_count = 0;

    // CPU Simulation State
    bool cpu_using_bus = true;
    int  cpu_grant_delay_counter = 0;

    Mud16System() {
        ppu = new Vppu;
        ram.resize(RAM_SIZE);
        memset(ram.data(), 0, RAM_SIZE);
        vram_init::load(ram);

        // Initial pin states
        ppu->clk = 0;
        ppu->reset = 1;
        ppu->cpu_bg_n = 1; // Not granted
        ppu->cpu_as_n = 1; // Address strobe inactive
        ppu->eval();
    }

    ~Mud16System() {
        delete ppu;
    }

    void init_ram_pattern() {
        for (int y = 0; y < HEIGHT; y++) {
            for (int x = 0; x < WIDTH; x++) {
                int addr = (y * WIDTH + x) * 4;
                if (addr + 3 < RAM_SIZE) {
                    ram[addr]     = (uint8_t)(x & 0xFF);
                    ram[addr + 1] = (uint8_t)(y & 0xFF);
                    ram[addr + 2] = (uint8_t)((x + y) & 0xFF);
                    ram[addr + 3] = 0xFF;
                }
            }
        }
    }

    void reset() {
        ppu->reset = 1;
        tick();
        tick();
        ppu->reset = 0;
    }

    // Run one clock cycle
    void tick() {
        // 1. Rising Edge
        ppu->clk = 1;
        ppu->eval();

        // 2. Simulate External Hardware (CPU & RAM)
        simulate_cpu_arbitration();
        simulate_memory();

        // 3. Falling Edge
        ppu->clk = 0;
        ppu->eval();

        tick_count++;
    }

private:
    void simulate_cpu_arbitration() {
        // --- CPU Logic ---

        // If PPU requests bus (BR low)
        if (ppu->ppu_br_n == 0) {
            // CPU takes some time to finish current instruction and release bus
            if (cpu_grant_delay_counter < 4) {
                cpu_grant_delay_counter++;
            } else {
                // Grant the bus
                ppu->cpu_bg_n = 0;

                // Release AS (Address Strobe) to indicate bus cycle finished
                ppu->cpu_as_n = 1;
            }
        } else {
            // No request, reset logic
            ppu->cpu_bg_n = 1;
            cpu_grant_delay_counter = 0;

            // If PPU is not master, CPU is master, so it might be pulsing AS
            if (ppu->ppu_bgack_n == 1) {
                // Simulate CPU activity (randomly pulsing AS)
                ppu->cpu_as_n = (tick_count % 4 == 0) ? 0 : 1;
            }
        }
    }

    void simulate_memory() {
        // Only respond if PPU is actually driving the bus
        if (ppu->ppu_bgack_n == 0 && ppu->cpu_bus_oe_n == 1) {

            if (ppu->mem_read) {
                uint32_t addr = ppu->mem_addr;
                if (addr + 3 < RAM_SIZE) {
                    ppu->mem_rdata = ram[addr] // 32 bit access
                                   | (ram[addr + 1] << 8)
                                   | (ram[addr + 2] << 16)
                                   | (ram[addr + 3] << 24);
                }
            }

            if (ppu->mem_write) {
                uint32_t addr = ppu->mem_addr;
                uint32_t data = ppu->mem_wdata;
                if (addr + 3 < RAM_SIZE) {
                    ram[addr]     = data & 0xFF; // 32 bit write
                    ram[addr + 1] = (data >> 8) & 0xFF;
                    ram[addr + 2] = (data >> 16) & 0xFF;
                    ram[addr + 3] = (data >> 24) & 0xFF;
                }
            }
        } else {
            // Bus is floating or driven by CPU (we ignore CPU memory access for this sim)
            ppu->mem_rdata = 0;

            // Log warning
            //printf("Warning: uhhh memory access attempted by PPU while CPU is driving the bus or bus is floating at tick %llu\n", tick_count);
        }
    }
};

// -----------------------------------------------------------------------------
// Main
// -----------------------------------------------------------------------------
int main() {
    Verilated::traceEverOn(true);

    Mud16System sys;
    sys.reset();

    InitWindow(WIDTH * SCALE, HEIGHT * SCALE, "mud-16 PPU");
    SetTargetFPS(60);

    // Framebuffer setup
    Image fbImage = GenImageColor(WIDTH, HEIGHT, BLACK);
    Texture2D fbTexture = LoadTextureFromImage(fbImage);
    unsigned char* pixels = (unsigned char*)fbImage.data;

    while (!WindowShouldClose()) {

        // Run some cycles
        for (int i = 0; i < WIDTH * HEIGHT; i++) {
            // Run PPU until pixel outputted
            while (sys.ppu->pixel_sync == 0) {
                sys.tick();
            }

            // Clear pixel data for new frame
            int base_idx = i * 4;
            pixels[base_idx + 0] = sys.ppu->pixel_r;
            pixels[base_idx + 1] = sys.ppu->pixel_g;
            pixels[base_idx + 2] = sys.ppu->pixel_b;
            pixels[base_idx + 3] = 255;

            // Tick again so the flag resets
            sys.tick();
        }

        UpdateTexture(fbTexture, pixels);

        BeginDrawing();
        ClearBackground(BLACK);
        DrawTextureEx(fbTexture, (Vector2){0, 0}, 0.0f, SCALE, WHITE);

        // Debug Overlay
        DrawFPS(10, 10);

        // Bus Status Indicator
        bool fpga_has_bus = (sys.ppu->ppu_bgack_n == 0);
        DrawRectangle(10, 30, 20, 20, fpga_has_bus ? GREEN : RED);
        DrawText(fpga_has_bus ? "FPGA MASTER" : "CPU MASTER", 35, 32, 20, WHITE);

        EndDrawing();
    }

    UnloadTexture(fbTexture);
    CloseWindow();

    return 0;
}

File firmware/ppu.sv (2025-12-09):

module ppu #(
    parameter DISP_WIDTH  = 320,
    parameter DISP_HEIGHT = 240,


    parameter MAX_OBJECTS = 128,

    parameter MAX_PALETTES = 8,
    parameter PALETTE_MEM_OFFSET = 18'h00000,
    parameter TILE_MEM_OFFSET    = 18'h01000,
    parameter BG_MAP_MEM_OFFSET  = 18'h05000,
    parameter UI_MAP_MEM_OFFSET  = 18'h06000,
    parameter OAM_MEM_OFFSET     = 18'h07000,

    // Memory timing
    parameter BUS_READ_LATENCY = 1

) (
    input  logic clk,
    input  logic reset,

    // Pixel outputs (VGA interface)
    output logic [7:0] pixel_r,
    output logic [7:0] pixel_g,
    output logic [7:0] pixel_b,
    output logic       pixel_sync,

    // 68000 Bus Arbitration Signals
    input  logic       cpu_bg_n,      // Bus Grant (Active Low) from CPU
    input  logic       cpu_as_n,      // Address Strobe (Active Low) from CPU
    output logic       ppu_br_n,      // Bus Request (Active Low) to CPU
    output logic       ppu_bgack_n,   // Bus Grant Acknowledge (Active Low) to CPU

    // Level Shifter Control
    output logic       cpu_bus_oe_n,  // Output Enable for CPU level shifters (Active Low = CPU drives bus)

    // Memory interface (Shared Bus)
    output logic [19:0] mem_addr,
    input  logic [15:0] mem_rdata,
    output logic [15:0] mem_wdata,
    output logic        mem_read,
    output logic        mem_write
);

    // -------------------------------------------------------------------------
    // Bus Arbitration State Machine
    // -------------------------------------------------------------------------
    typedef enum logic [3:0] {
        IDLE,
        REQUEST_BUS,
        SEIZE_BUS,
        BUS_MASTER,
        READ_REQ,
        READ_WAIT,
        WRITE_REQ,
        WRITE_WAIT,
        RELEASE_BUS
    } bus_state_t;

    bus_state_t bus_state;
    reg  [7:0]  bus_wait_cnt;
    reg  [15:0] bus_rdata_latched;
    reg  [15:0] bus_wdata_latched;
    reg  [19:0] bus_addr_latched;
    reg         bus_op_done;
    reg         cpu_as_high_seen;

    // Internal requests
    logic want_bus;
    logic bus_req_read;
    logic bus_req_write;
    logic need_mem_refresh;
    logic mem_refreshed;

    // Memory arrays
    reg [11:0] palette [0:7][0:15];      // 8 palettes, 16 colors each, 12-bit RGB
    reg [7:0]  tile_memory [0:16383];    // 512 tiles * 32 bytes = 16KB
    reg [31:0] oam [0:MAX_OBJECTS-1];    // Object Attribute Memory

    reg [7:0]  bg_tile_map [0:4095];     // Background tile map (64x64 tiles = 4096 bytes)
    reg [2:0]  bg_palette;               // Background palette index

    reg [7:0]  ui_tile_map [0:399];      // UI tile map (40x10 tiles = 400 bytes; UI only at the top and bottom)
    reg [2:0]  ui_top_palette;           // UI palette index (top)
    reg [2:0]  ui_bottom_palette;        // UI palette index (bottom)

    // Memory Refresh FSM signals
    typedef enum logic [3:0] {
        REFRESH_IDLE,
        REFRESH_PALETTES,
        REFRESH_WAIT_PALETTE,
        REFRESH_TILES,
        REFRESH_WAIT_TILE,
        REFRESH_BG_MAP,
        REFRESH_WAIT_BG_MAP,
        REFRESH_UI_MAP,
        REFRESH_WAIT_UI_MAP,
        REFRESH_OAM,
        REFRESH_WAIT_OAM_LOW,
        REFRESH_WAIT_OAM_HIGH,
        REFRESH_DONE
    } refresh_state_t;

    refresh_state_t refresh_state;
    logic refresh_wait_mem;
    logic [3:0] refresh_palette;

    // MEMORY FSM

    always_ff @(posedge clk) begin
        if (reset) begin
            mem_addr          <= 0;
            mem_wdata         <= 0;
            mem_read          <= 0;
            mem_write         <= 0;
            cpu_bus_oe_n      <= 0; // Default: CPU enabled
            ppu_br_n          <= 1;
            ppu_bgack_n       <= 1;
            bus_state         <= IDLE;
            bus_wait_cnt      <= 0;
            bus_rdata_latched <= 0;
            bus_op_done       <= 0;
            cpu_as_high_seen  <= 0;
        end else begin
            // default strobes low each cycle
            mem_read  <= 0;
            mem_write <= 0;

            case (bus_state)
                IDLE: begin
                    ppu_br_n     <= 1;
                    ppu_bgack_n  <= 1;
                    cpu_bus_oe_n <= 0; // CPU drives bus
                    if (want_bus) begin
                        ppu_br_n  <= 0;
                        bus_state <= REQUEST_BUS;
                    end
                end

                REQUEST_BUS: begin
                    ppu_br_n <= 0; // hold request
                    cpu_as_high_seen <= cpu_as_n;
                    if (!cpu_bg_n && cpu_as_n && cpu_as_high_seen) begin
                        bus_state <= SEIZE_BUS; // CPU granted and AS high for a full cycle
                    end
                end

                SEIZE_BUS: begin
                    ppu_bgack_n  <= 0; // take bus
                    cpu_bus_oe_n <= 1; // disable CPU drivers
                    bus_wait_cnt <= 0;
                    bus_state    <= BUS_MASTER;
                end

                BUS_MASTER: begin
                    bus_op_done <= 0;
                    if (!want_bus) begin
                        bus_state <= RELEASE_BUS;
                    end else if (bus_req_read) begin
                        bus_state <= READ_REQ;
                    end else if (bus_req_write) begin
                        bus_state <= WRITE_REQ;
                    end
                end

                READ_REQ: begin
                    mem_addr <= bus_addr_latched;
                    mem_read  <= 1;
                    bus_state <= READ_WAIT;
                end

                READ_WAIT: begin
                    if (bus_wait_cnt < BUS_READ_LATENCY - 1) begin
                        bus_wait_cnt <= bus_wait_cnt + 1;
                    end else begin
                        bus_rdata_latched <= mem_rdata;
                        if (!want_bus) begin
                            bus_state <= RELEASE_BUS;
                        end else begin
                            bus_wait_cnt <= 0;
                            bus_state    <= BUS_MASTER;
                            bus_op_done <= 1;
                        end
                    end
                end

                WRITE_REQ: begin
                    mem_addr  <= bus_addr_latched;
                    mem_wdata <= bus_wdata_latched;
                    mem_write <= 1;
                    bus_state <= WRITE_WAIT;
                end

                WRITE_WAIT: begin
                    if (bus_wait_cnt < BUS_READ_LATENCY - 1) begin
                        bus_wait_cnt <= bus_wait_cnt + 1;
                    end else begin
                        if (!want_bus) begin
                            bus_state <= RELEASE_BUS;
                        end else begin
                            bus_wait_cnt <= 0;
                            bus_state    <= BUS_MASTER;
                            bus_op_done <= 1;
                        end
                    end
                end
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

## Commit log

2025-12-04 Renders, but broken for now. Probably because some sync signals are needed. Also high CPU usage, need to fix that.
    [main.cpp, ppu.sv]
2025-12-11 add PCB for now (not finished)
    [display.kicad_sch, inputs.kicad_sch, logicshifters.kicad_sch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]
2025-12-13 Placed components on PCB
    [display.kicad_sch, inputs.kicad_sch, logicshifters.kicad_sch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]
2025-12-14 routing pcb
    [logicshifters.kicad_sch, mud-16.kicad_pcb, mud-16.kicad_sch]
2025-12-15 almost done routing
    [logicshifters.kicad_sch, mud-16.kicad_pcb]
2025-12-15 finish routing
    [mud-16.kicad_pcb]
2025-12-16 extra files
    [BOM.csv, Case.f3z]
2025-12-18 remove fusion file
    [Case.f3z]
2025-12-18 update BOM
    [BOM.csv]
2025-12-18 Add schematic screenshots section to README
    Added schematic screenshots to the README.
2025-12-23 edit BOM
    [BOM.csv]
2025-12-23 changes to BOM
    [BOM.csv]
2025-12-24 update links
    [BOM.csv]
2025-12-28 Remove logic analyzer and helping hands from BOM.csv and README.md
    [BOM.csv]
2025-12-28 Update prices: MC68000P12 to $4.96 and AS7C3513B-12TCN to $12.96
    [BOM.csv]
2026-01-02 Replace PCB + PCBA with separate PCB and PCB Assembly entries
    [BOM.csv]
2026-01-02 Revise PCB description in the README
    Updated PCB entry to reflect changes in description.
2026-01-02 Update PCB description in BOM.csv
    [BOM.csv]
2026-01-02 Add 11 new PCBA parts to BOM.csv and README.md
    [BOM.csv]
2026-03-31 Remove old BOM
